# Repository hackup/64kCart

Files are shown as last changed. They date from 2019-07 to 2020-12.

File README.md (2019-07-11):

# 64kCart

The 64kCart is a simple bank switching cartridge for the C64/C128. It is a remake of the ["64k-Karte"](http://www.idealine.info/emuecke/index_quereinstieg.htm?/emuecke/hardware/64k_modulkart.htm) created by Hucky which supports EPROM types 2764 up to 27512.

There is also no warranty whatsoever. **USE AT YOUR OWN RISK!**.

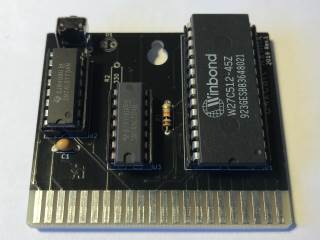
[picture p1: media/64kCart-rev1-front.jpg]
64kCart Rev.1 Front


See my [blog post](https://www.hackup.net/2019/07/bank-switching-cartridges/) for more details.

## License


This work is licensed under a
[Creative Commons Attribution-NonCommercial-ShareAlike 4.0 International License](http://creativecommons.org/licenses/by-nc-sa/4.0/).

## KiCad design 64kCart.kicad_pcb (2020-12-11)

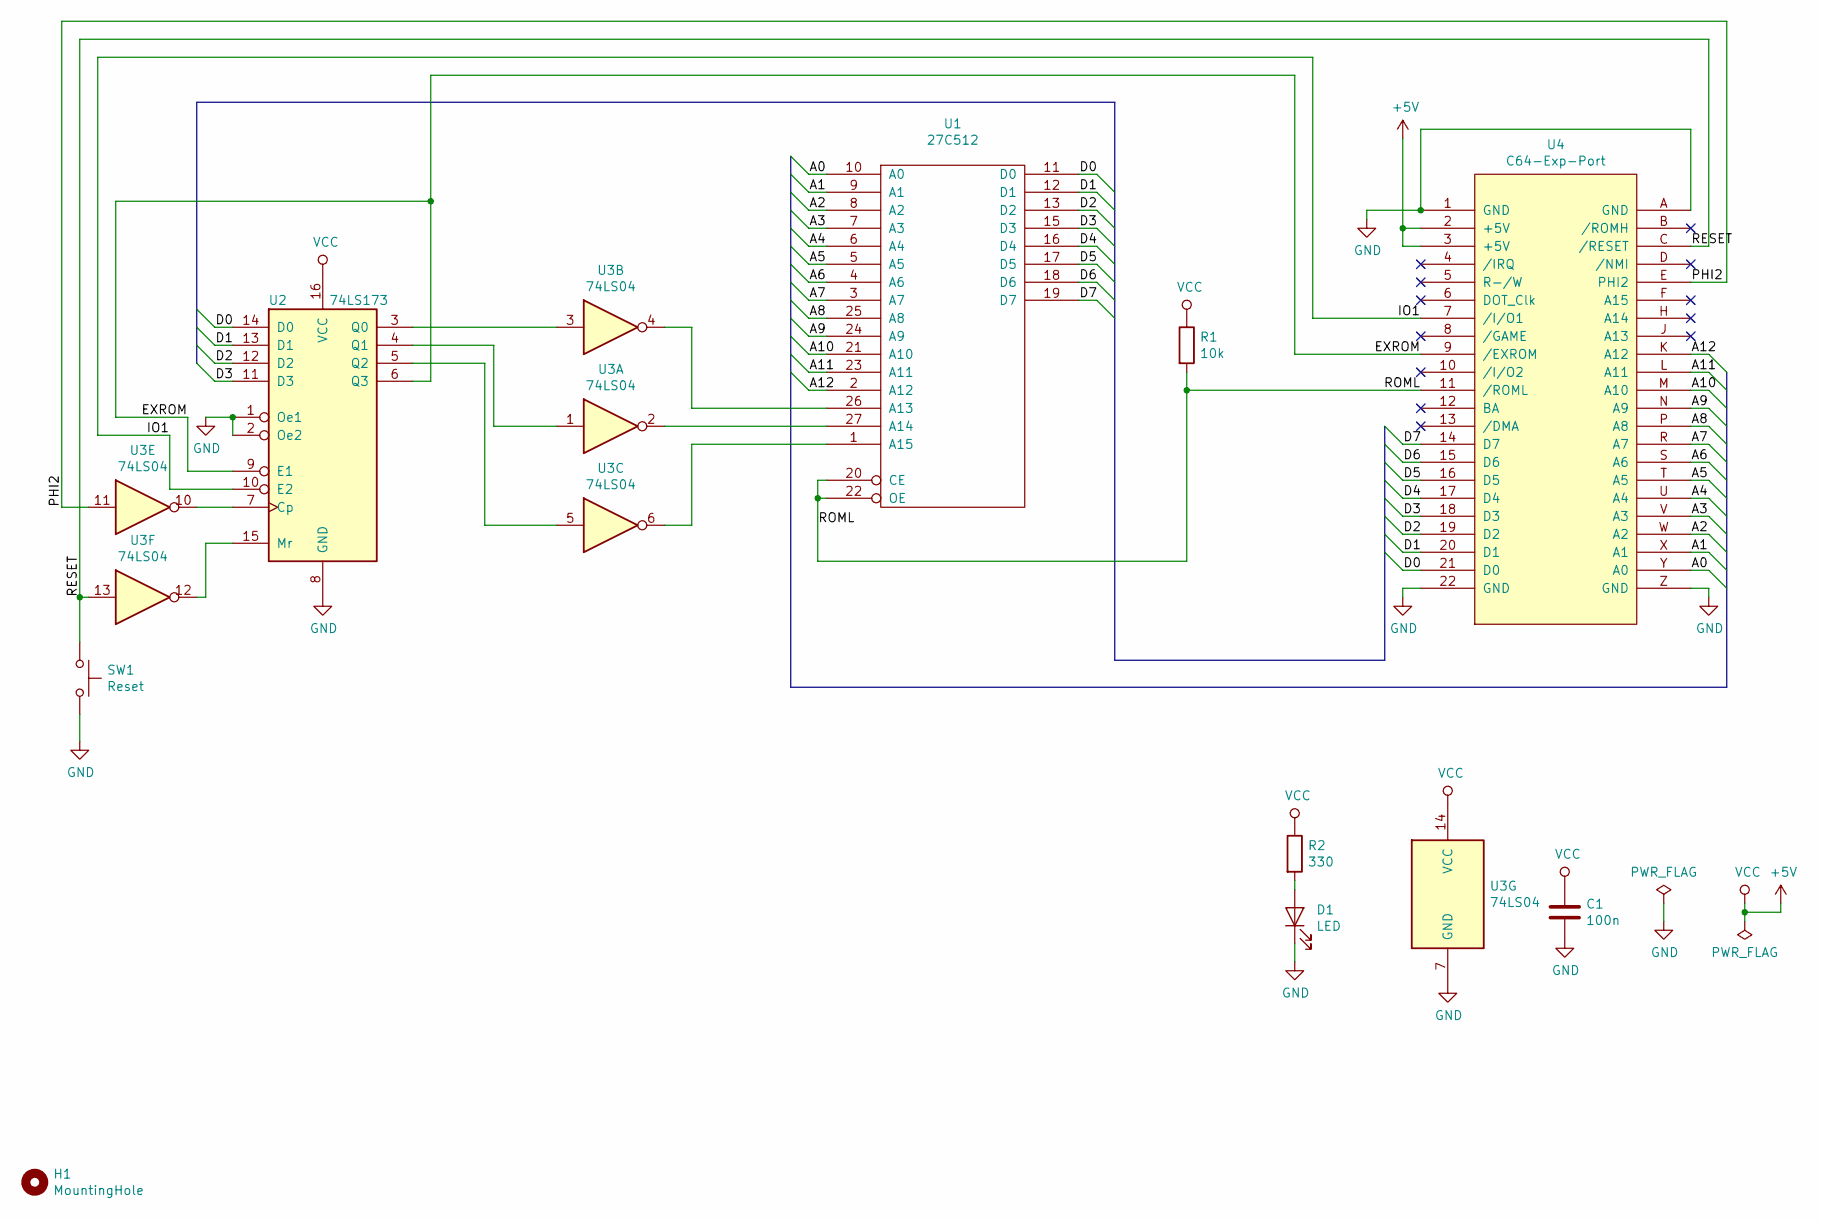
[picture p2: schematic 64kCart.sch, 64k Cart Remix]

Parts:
C1: 100n; C_Disc_D4.3mm_W1.9mm_P5.00mm
D1: LED; LED_D3.0mm
H1: MountingHole; MountingHole_CartCombined
R1: 10k; R_Axial_DIN0207_L6.3mm_D2.5mm_P7.62mm_Horizontal
R2: 330; R_Axial_DIN0207_L6.3mm_D2.5mm_P7.62mm_Horizontal
SW1: Reset; SW_Tactile_SPST_Angled_PTS645Vx83-2LFS
U1: 27C512; DIP-28_W15.24mm_Socket
U2: 74LS173; DIP-16_W7.62mm_Socket
U3: 74LS04; DIP-14_W7.62mm_Socket
U4: C64-Exp-Port; C64-Cart-NoSilkS

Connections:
+5V: C1.1, R1.1, R2.1, U1.28 (VCC), U2.16 (VCC), U3.14 (VCC), U4.2 (+5V), U4.3 (+5V)
/A0: U1.10 (A0), U4.Y (A0)
/A1: U1.9 (A1), U4.X (A1)
/A2: U1.8 (A2), U4.W (A2)
/A3: U1.7 (A3), U4.V (A3)
/A4: U1.6 (A4), U4.U (A4)
/A5: U1.5 (A5), U4.T (A5)
/A6: U1.4 (A6), U4.S (A6)
/A7: U1.3 (A7), U4.R (A7)
/A8: U1.25 (A8), U4.P (A8)
/A9: U1.24 (A9), U4.N (A9)
/A10: U1.21 (A10), U4.M (A10)
/A11: U1.23 (A11), U4.L (A11)
/A12: U1.2 (A12), U4.K (A12)
/D0: U1.11 (D0), U2.14 (D0), U4.21 (D0)
/D1: U1.12 (D1), U2.13 (D1), U4.20 (D1)
/D2: U1.13 (D2), U2.12 (D2), U4.19 (D2)
/D3: U1.15 (D3), U2.11 (D3), U4.18 (D3)
/D4: U1.16 (D4), U4.17 (D4)
/D5: U1.17 (D5), U4.16 (D5)
/D6: U1.18 (D6), U4.15 (D6)
/D7: U1.19 (D7), U4.14 (D7)
/EXROM: U2.6 (Q3), U2.9 (E1), U4.9 (/EXROM)
/IO1: U2.10 (E2), U4.7 (/I/O1)
/PHI2: U3.11, U4.E (PHI2)
/RESET: SW1.1, U3.13, U4.C (/RESET)
/ROML: R1.2, U1.20 (CE), U1.22 (OE), U4.11 (/ROML)
GND: C1.2, D1.1 (K), SW1.2, U1.14 (GND), U2.1 (Oe1), U2.2 (Oe2), U2.8 (GND), U3.7 (GND), U4.1 (GND), U4.22 (GND), U4.A (GND), U4.Z (GND)
unnamed: D1.2 (A), R2.2
unnamed: U1.1 (A15), U3.6
unnamed: U1.26 (A13), U3.4
unnamed: U1.27 (A14), U3.2
unnamed: U2.3 (Q0), U3.3
unnamed: U2.4 (Q1), U3.1
unnamed: U2.5 (Q2), U3.5
unnamed: U2.7 (Cp), U3.10
unnamed: U2.15 (Mr), U3.12

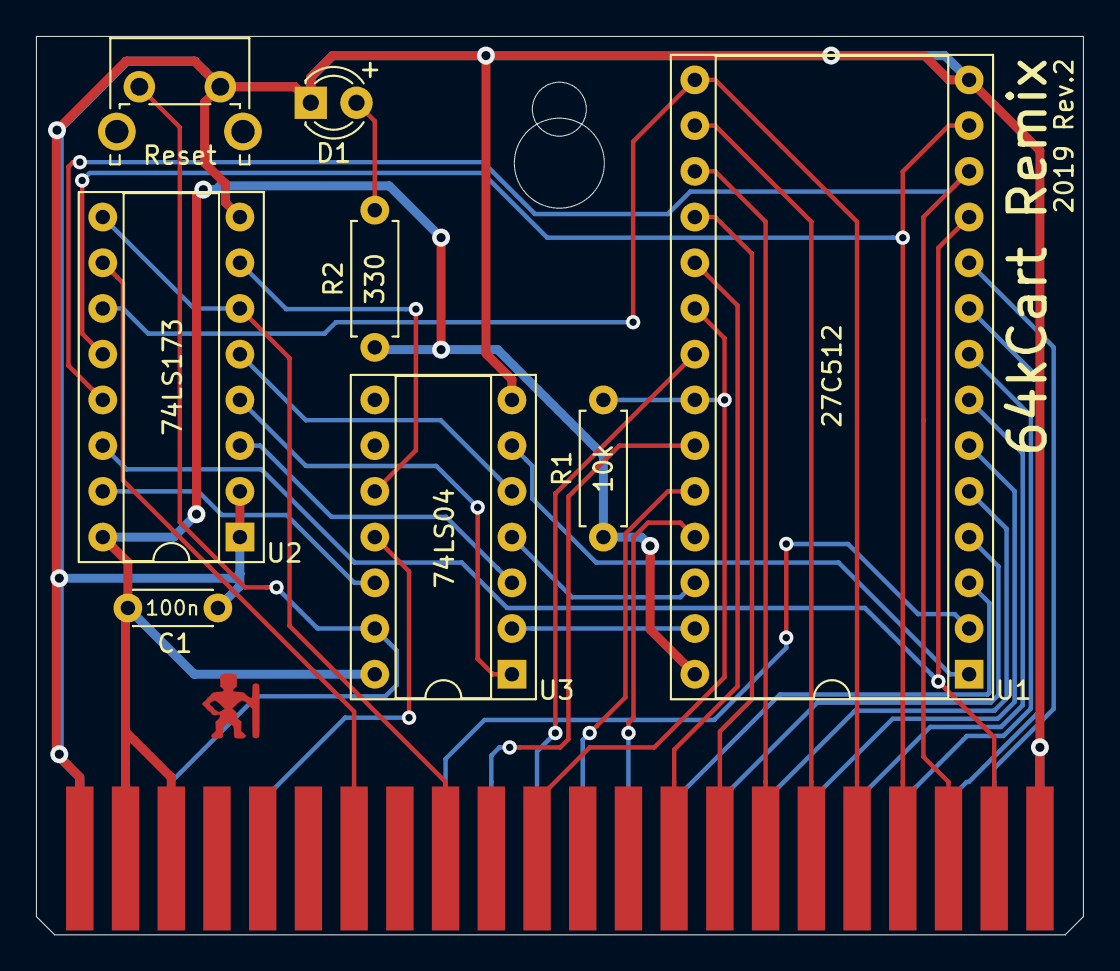
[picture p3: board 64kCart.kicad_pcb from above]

Board: 2 copper layers, 58.2 x 49.9 mm, 10 parts (0 on the bottom side), 37 nets.

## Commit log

2019-05-05 Initial commit.
    [64kCart.kicad_pcb, 64kCart.sch]
2019-05-05 Assigned first footprints.
    [64kCart.kicad_pcb, 64kCart.sch]
2019-05-05 Minor improvements.
    [64kCart.sch]
2019-05-06 Some work on board layout.
    [64kCart.kicad_pcb, 64kCart.sch]
2019-05-06 First layout completed.
    [64kCart.kicad_pcb, 64kCart.sch]
2019-05-06 First gerber export.
    [64kCart.kicad_pcb]
2019-05-07 Mark LED orientation.
    [64kCart.kicad_pcb]
2020-12-11 Minor updates for revision 2.
    [64kCart.kicad_pcb]
